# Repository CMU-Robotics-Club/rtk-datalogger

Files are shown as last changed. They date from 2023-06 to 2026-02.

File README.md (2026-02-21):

# Buggy Datalogger

[Software setup guide](https://docs.google.com/document/d/1eP9aE6b0Ft-kowX-BL1zWn5er9YviGEOUXOAjJxQ_KY/edit?tab=t.0)

Assembeled hardware:
<p align="center">
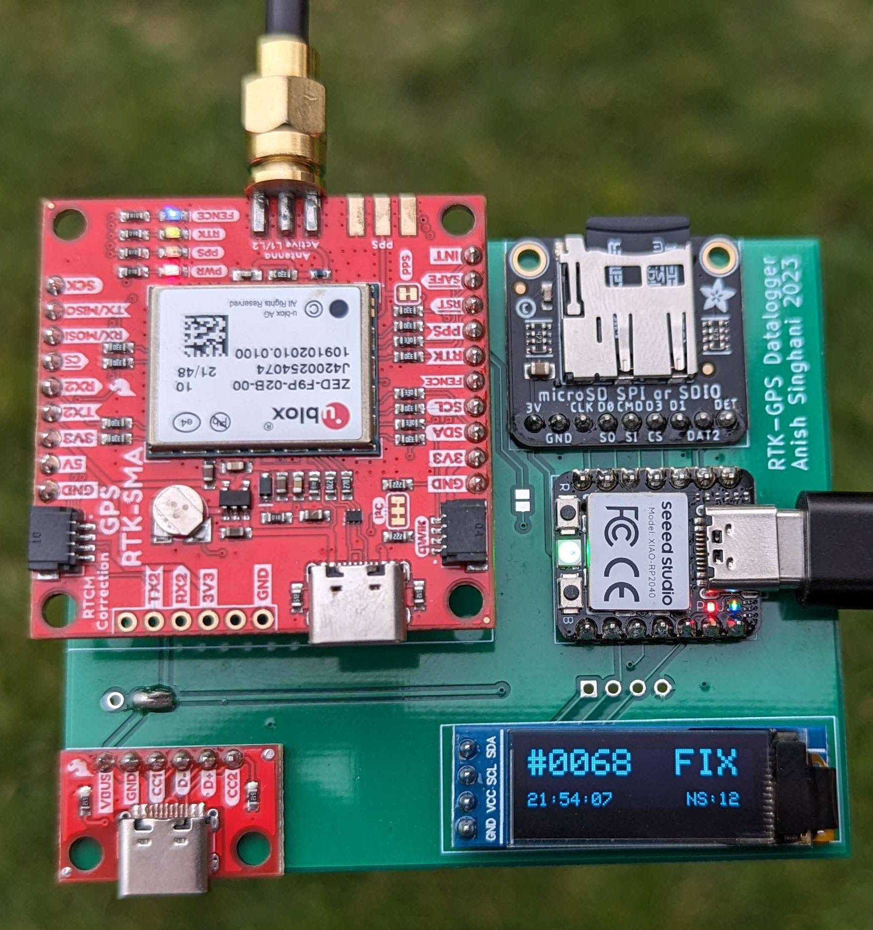
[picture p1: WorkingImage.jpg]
Image showing a module running a preliminary version of v1.0 Arduino firmware.

<p align="center">Image showing a module running a preliminary version of v1.0 Arduino firmware.</p>
</p>

[Project details](https://docs.google.com/document/d/1rpgdQh8PU_HBcYY4pXCmuHVJJGmpP6dXH_ktl7bgED4/edit?usp=sharing)

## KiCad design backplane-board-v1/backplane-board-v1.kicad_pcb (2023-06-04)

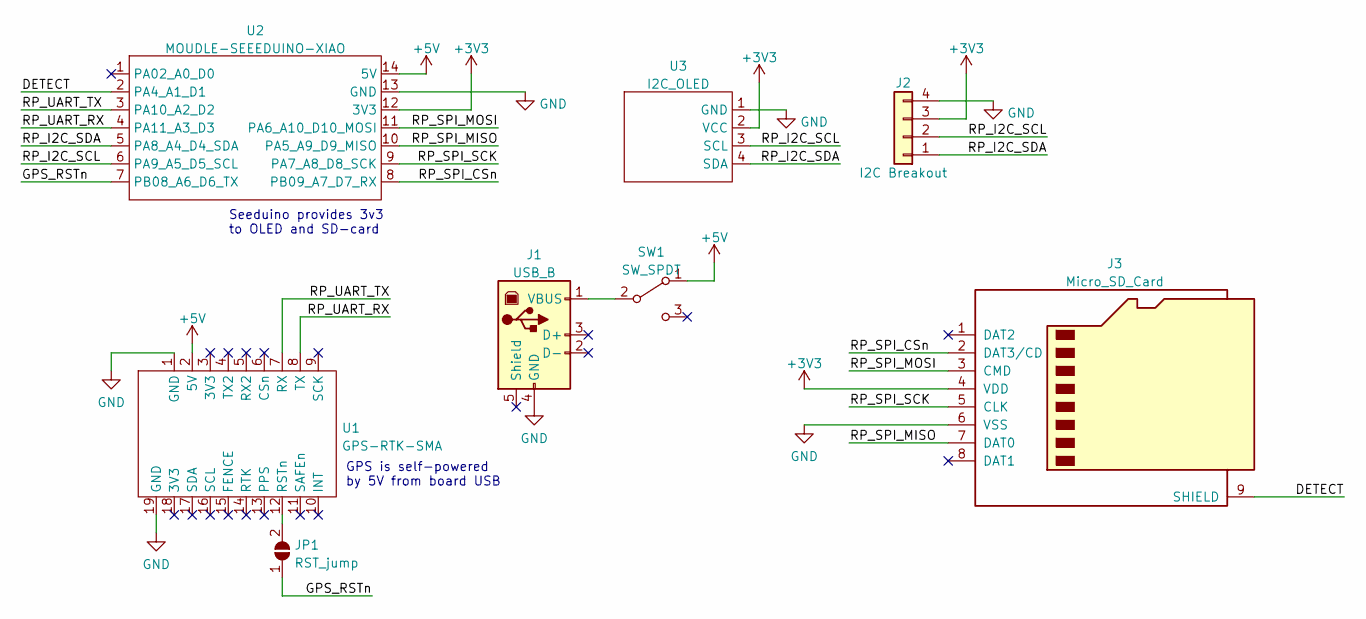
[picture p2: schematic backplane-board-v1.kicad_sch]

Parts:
J1: USB_B; sparkfun_usbc
J2: I2C Breakout; PinHeader_1x04_P2.54mm_Vertical
J3: Micro_SD_Card; adafruit_microsd
JP1: RST_jump; SolderJumper-2_P1.3mm_Open_Pad1.0x1.5mm
SW1: SW_SPDT; PinHeader_1x03_P2.54mm_Vertical
U1: GPS-RTK-SMA; gps-rtk-sma
U2: MOUDLE-SEEEDUINO-XIAO; MOUDLE14P-2.54-21X17.8MM
U3: I2C_OLED; i2c-oled

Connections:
+3V3: J2.3, J3.4 (VDD), U2.12 (3V3), U3.2 (VCC)
+5V: SW1.1 (A), U1.2 (5V), U2.14 (5V)
/DETECT: J3.9 (SHIELD), U2.2 (PA4_A1_D1)
/GPS_RSTn: JP1.1 (A), U2.7 (PB08_A6_D6_TX)
/RP_I2C_SCL: J2.2, U2.6 (PA9_A5_D5_SCL), U3.3 (SCL)
/RP_I2C_SDA: J2.1, U2.5 (PA8_A4_D4_SDA), U3.4 (SDA)
/RP_SPI_CSn: J3.2 (DAT3/CD), U2.8 (PB09_A7_D7_RX)
/RP_SPI_MISO: J3.7 (DAT0), U2.10 (PA5_A9_D9_MISO)
/RP_SPI_MOSI: J3.3 (CMD), U2.11 (PA6_A10_D10_MOSI)
/RP_SPI_SCK: J3.5 (CLK), U2.9 (PA7_A8_D8_SCK)
/RP_UART_RX: U1.8 (TX), U2.4 (PA11_A3_D3)
/RP_UART_TX: U1.7 (RX), U2.3 (PA10_A2_D2)
GND: J1.4 (GND), J2.4, J3.6 (VSS), U1.1 (GND), U1.19 (GND), U2.13 (GND), U3.1 (GND)
unnamed: J1.1 (VBUS), SW1.2 (B)
unnamed: JP1.2 (B), U1.12 (RSTn)

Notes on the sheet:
Seeduino provides 3v3 to OLED and SD-card
GPS is self-powered by 5V from board USB

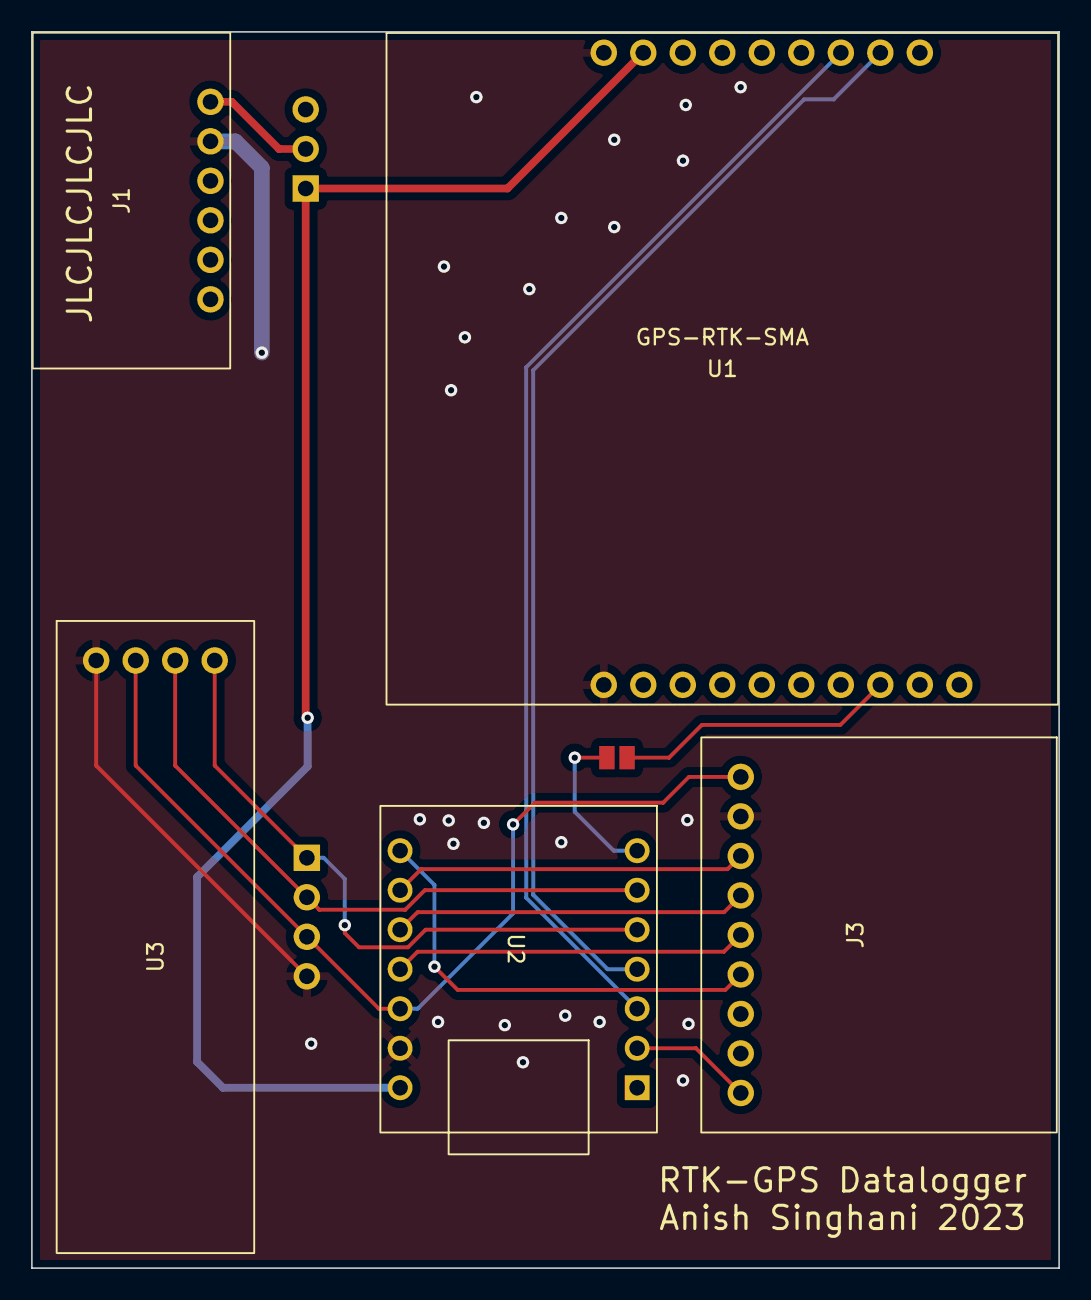
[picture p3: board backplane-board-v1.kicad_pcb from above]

Board: 2 copper layers, 66.0 x 79.5 mm, 8 parts (0 on the bottom side), 15 nets.

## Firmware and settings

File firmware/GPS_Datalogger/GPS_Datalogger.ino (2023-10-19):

// GPS Datalogger Arduino Firmware v1.0
//  for RTK-GPS Datalogger, A.S. 2023
//  (Seeed XIAO RP2040 + Sparkfun ZED-F9P breakout)
// By Robert Mones

#define PIN_SD_MOSI 3
#define PIN_SD_MISO 4
#define PIN_SD_SCK  2
#define PIN_SD_SS   1

#include <SPI.h>
#include <RP2040_SD.h>

#include <Adafruit_NeoPixel.h>
#include <Adafruit_GFX.h>
#include <Adafruit_SSD1306.h>
#include <splash.h>

// Uncomment the following line to enable debug mode
//  In debug mode, some testing data is printed to the USB serial port
//  and the system does not start until something is sent to it via the
//  USB serial port. The device will still print error messages via the
//  USB serial port regardless of this setting.
// #define DEBUG

// Size of the data buffer (in bytes)
#define BUFSIZE (1024*32)
// Minimum amount of data to copy from the buffer to the SD card
#define WRITESIZE (1024*1)

// Hardware UART interface to communicate with the GPS module
SerialPIO gps_uart(28, 29);
int fixtype = 0;

// NeoPixel object to control the onboard RGB LED
Adafruit_NeoPixel rgb(1, 12, NEO_GRB + NEO_KHZ800);
uint32_t ledtime = 0;
bool ledstate = 0;

// Display object to communicate with the SSD1306 display over I2C
Adafruit_SSD1306 disp(128, 32, &Wire, -1);

// Data buffers and their respective sizes
size_t bufct = 0;
size_t bufcpyct = 0;
size_t bufctmax = 0;
uint8_t buf[BUFSIZE];
uint8_t bufcpy[BUFSIZE];

// File object which is being written to on the SD card
char fname[30];
File datafile;

// Flag which is set if an error occurs
volatile bool error_flag = false;
// Helper function which flashes the RGB led red, prints an error message to the display
//  (if msg != NULL), and prints an error message to the USB serial port (if dbgmsg != NULL)
void error(char *msg, char *dbgmsg) {
  error_flag = true;
  delay(1000);
  rgb.clear();
  rgb.setPixelColor(0, rgb.Color(127,0,0));
  rgb.show();

  if(dbgmsg != NULL) {
    Serial.println(dbgmsg);
  }

  if(msg != NULL) {
    disp.clearDisplay();
    disp.setTextSize(2);
    disp.setCursor(0,0);
    disp.write(msg);
    disp.display();
  }

  while(true) {
    rgb.clear();
    rgb.setPixelColor(0, rgb.Color(127,0,0));
    rgb.show();
    delay(250);
    rgb.clear();
    rgb.setPixelColor(0, rgb.Color(0,0,0));
    rgb.show();
    delay(250);
  }
}

void setup() {
  // Init debug USB serial port
  Serial.begin(115200);
  #ifdef DEBUG
  while(!Serial.available());
  while(Serial.available()) Serial.read();
  Serial.println("Starting GPS Datalogger");
  #endif

  // Init RGB led
  rgb.begin();
  pinMode(11, OUTPUT);
  digitalWrite(11, HIGH);
  rgb.clear();
  rgb.setPixelColor(0, rgb.Color(31,31,0));
  rgb.show();

  // Init display
  if(!disp.begin(SSD1306_SWITCHCAPVCC, 0x3C)) {
    error(NULL, "FAILED TO INIT DISPLAY");
  }
  disp.clearDisplay();
  disp.setTextSize(2);
  disp.setTextColor(SSD1306_WHITE);
  disp.display();

  memset(buf, 0, BUFSIZE);
  memset(bufcpy, 0, BUFSIZE);

  // Init SD card
  SPI.setRX(PIN_SD_MISO);
  SPI.setCS(PIN_SD_SS);
  SPI.setSCK(PIN_SD_SCK);
  SPI.setTX(PIN_SD_MOSI);
  if (!SD.begin(PIN_SD_SS)) {
    error("NO SD CARD", "FAILED TO INIT SD CARD");
  }
  // Search for filename
  for (uint32_t i = 0; i < 10000; i++) {
    sprintf(fname, "DATA%04d.BIN", i);
    if (!SD.exists(fname)) break;
  }
  // Create the new file and overwrite if existing, but this won't happen
  //  until file cap is reached
  if (SD.exists(fname)) SD.remove(fname);
  datafile = SD.open(fname, FILE_WRITE);
  if (!datafile) {
    char printbuf[40];
    sprintf(printbuf, "FAILED TO OPEN FILE %s", fname);
    error("FAILED TO OPEN FILE", printbuf);
  }
  #ifdef DEBUG
  Serial.print("uSD Card initialized -- writing to ");
  Serial.println(fname);
  #endif
  // Delay to let everything power up
  delay(1000);

  // Tell other core to begin loop and wait for it to be ready
  rp2040.fifo.push(1);
  rp2040.fifo.pop();
}

void loop() {
  // Check buffer usage
  if (bufct > WRITESIZE) {
    if(bufct > bufctmax) bufctmax = bufct;
    // Ask for custody of buf from core1 and proceed on positive response
    rp2040.fifo.push_nb(1);
    if (rp2040.fifo.pop() == 1) {
      // Copy buf to bufcpy
      memcpy(bufcpy, buf, bufct);
      bufcpyct = bufct;
      bufct = 0;
      // Finish copy by giving custody of buf back to core1
      rp2040.fifo.push(0);

      // Write copied data to SD card
      if(datafile.write(bufcpy, bufcpyct) < bufcpyct) {
        error("FILE WRITE  FAILED", "FAILED TO WRITE TO FILE");
      }
      datafile.flush();

      #ifdef DEBUG
      Serial.print("Wrote ");
      Serial.print(bufcpyct);
      Serial.println(" bytes");
      #endif

      // Parse GNGGA NMEA packet to get utc time, fix type, and number of satellites
      // Start from end of data being written to only consider latest packet
      size_t nmea_start = 0;
      size_t nmea_end = 0;
      size_t i = bufcpyct - 1;
      for(; i >= 4; i--) {
        // Look for end of NMEA packet
        if(bufcpy[i-4] == '*' &&
            ((bufcpy[i-3] >= '0' && bufcpy[i-3] <= '9') || (bufcpy[i-3] >= 'A' && bufcpy[i-3] <= 'F')) &&
            ((bufcpy[i-2] >= '0' && bufcpy[i-2] <= '9') || (bufcpy[i-2] >= 'A' && bufcpy[i-2] <= 'F')) &&
            bufcpy[i-1] == '\r' && bufcpy[i] == '\n') {
          nmea_end = i-1; // Exclusive end of NMEA string
          break;
        }
      }
      for(; i >= 1; i--) {
        // Look for start of NMEA packet
        if(strncmp("$GNGGA", (char*)(bufcpy+i-1), 6) == 0) {
          nmea_start = i-1; // Inclusive start of GNGGA NMEA string
          break;
        }
      }
      size_t nmea_len = nmea_end - nmea_start;
      if(nmea_len >= 6 && nmea_len <= 82) {
        // Found valid GNGGA NMEA packet
        char gnggabuf[100];
        memcpy(gnggabuf, bufcpy+nmea_start, nmea_len);
        // Need to separate commas and replace with spaces to support easy sscanf parsing
        for(size_t j = 1; j < nmea_len; j++) {
          if(gnggabuf[j-1] == ',' && gnggabuf[j] == ',') {
            memmove(gnggabuf+j+1, gnggabuf+j, nmea_len-j);
            gnggabuf[j] = 'x';
            nmea_len++;
          }
        }
        for(size_t j = 0; j < nmea_len; j++) {
          if(gnggabuf[j] == ',') gnggabuf[j] = ' ';
        }
        gnggabuf[nmea_len] = '\0';

        #ifdef DEBUG
        Serial.print("Extracted packet '");
        Serial.print(gnggabuf);
        Serial.println("'");
        #endif

        // Parse relevant information from packet
        char utcbuf[10];
        int tmpfixtype = -1;
        int numsats = -1;
        int parsect = sscanf(gnggabuf, "$GNGGA %s %*s %*s %*s %*s %d %d %*s %*s %*s %*s %*s *%*s", utcbuf, &tmpfixtype, &numsats);
        utcbuf[9] = '\0';
        
        #ifdef DEBUG
        Serial.print("Parsed (");
        Serial.print(parsect);
        Serial.print(") ");
        Serial.print(utcbuf);
        Serial.print(" time, ");
        Serial.print(fixtype);
        Serial.print(" fix, ");
        Serial.print(numsats);
        Serial.println(" satellites");
        #endif

        // If parse succeeded, proceed with storing fix type in global variable and
        //  write to display
        if(parsect == 3) {
          fixtype = tmpfixtype;
          // Write to display
          disp.clearDisplay();
          disp.setTextSize(2);
          disp.setCursor(0,0);
          char printbuf[11];
          sprintf(printbuf, "#%c%c%c%c  %s", fname[4], fname[5], fname[6], fname[7], (fixtype > 0) ? "FIX" : "---");
          disp.write(printbuf);
          disp.write("\n");
          int utchr = -1;
          int utcmin = -1;
          int utcsec = -1;
          sscanf(utcbuf, "%02d%02d%02d.%*02d", &utchr, &utcmin, &utcsec);
          sprintf(printbuf, "%02d:%02d:%02d     Sats:%02d", utchr, utcmin, utcsec, numsats);
          disp.setTextSize(1);
          disp.write("\n");
          disp.write(printbuf);
          disp.display();
        }
      }
      
      delay(10);
    }
  }

  // Flash RGB LED blue if no fix and green if fix
  uint32_t t = millis();
  if(t - ledtime > 500) {
    ledtime = t;
    ledstate = !ledstate;
    
    rgb.clear();
    rgb.setPixelColor(0, ledstate ? (fixtype > 0 ? rgb.Color(0,31,0) : rgb.Color(0,0,63)) : rgb.Color(0,0,0));
    rgb.show();
  }

  // Halt while error_flag is set to true
  while(error_flag);
}

void setup1() {
  // Open the hardware UART port to the GPS module
  gps_uart.begin(460800);

  // Wait for the other core to be ready and tell it this core is ready
  rp2040.fifo.pop();
  rp2040.fifo.push(1);
}

void loop1() {
  // Read the data from the GPS module into the buffer
  while (gps_uart.available()) {
    buf[bufct] = gps_uart.read();
    bufct++;
    if(bufct >= BUFSIZE) {
      error("BUFFER    OVERFLOW", "BUFFER OVERFLOW");
    }
  }
  uint32_t coremsg;
  // Check if a request for buf custody is present
  if (rp2040.fifo.pop_nb(&coremsg) && coremsg == 1) {
    // Respond giving custody to core0
    rp2040.fifo.push_nb(1);
    // Wait for custody back from core1
    uint32_t t1 = micros();
    while (rp2040.fifo.pop() != 0);
    uint32_t t2 = micros();
    #ifdef DEBUG
    Serial.print("Waited ");
    Serial.print(t2 - t1);
    Serial.println(" us");
    #endif
  }

  // Halt while error_flag is set to true
  while(error_flag);
}

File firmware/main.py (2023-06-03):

import machine
import sdcard
import uos
import time
import _thread
import hashlib
import neopixel


SPI_PERIPH = 1
CS_PIN = 9
SCK_PIN = 14
MOSI_PIN = 15
MISO_PIN = 12
SD_BAUD = 25000000

UART_PERIPH = 0
UART_TX_PIN = 28
UART_RX_PIN = 29
UART_BAUD = 230400

WS2812_PIN = 8

BLOCK_SIZE = 16
WRITE_CHUNK_SIZE = 8192
CHUNK_SIZE = 1*WRITE_CHUNK_SIZE
FILE_TIME = 5 # seconds

WDT_TIMER = 7000 # watchdog timeout, millis

DO_ENCRYPT = False
ENCRYPT_KEY = ""

VERSION = "0.1.4"

# TODO: This is effectively just a shim. need 
# to implement proper asymmetric-key encryption
# with the key stored on the SD card. This will
# ensure that the key used for decryption is not
# stored anywhere on the embedded device.
def encrypt(plaintext, iv):
    if DO_ENCRYPT:
        cipher = hashlib.sha256(ENCRYPT_KEY+iv).digest()
        ciphertext = bytearray([plaintext[i] ^ cipher[i % BLOCK_SIZE]
                      for i in range(len(plaintext))])
        return iv, ciphertext
    else:
        return iv, plaintext

def panic(reason):
    while True:
        print("PANIC:", reason)
        time.sleep(1)

def setup_sdcard():
    cs = machine.Pin(CS_PIN, machine.Pin.OUT)
    spi = machine.SPI(SPI_PERIPH, baudrate=SD_BAUD,
        polarity=0, phase=0, bits=8,
        firstbit=machine.SPI.MSB,
        sck=machine.Pin(SCK_PIN),
        mosi=machine.Pin(MOSI_PIN),
        miso=machine.Pin(MISO_PIN))

    sd = sdcard.SDCard(spi, cs)

    vfs = uos.VfsFat(sd)
    uos.mount(vfs, "/sd")

def get_next_index():
    cur_idx = None
    try:
        with open("/sd/index.txt", "r") as f:
            cur_idx = int(f.read().strip())
    except:
        pass

    if cur_idx:
        try:
            with open("/sd/index.txt", "w+") as f:
                f.write(str(cur_idx+1))
            return cur_idx+1
        except:
            panic("Failed to increment index")
    else:
        try:
            with open("/sd/index.txt", "w+") as f:
                f.write(str(1))
            return 1
        except:
            panic("Failed to create new index file")

def get_next_filename():
    wdt.feed();
    idx = get_next_index()
    fn = "/sd/gps{:06d}.txt".format(idx)

    wdt.feed();
    print("Starting file", fn)
    with open(fn, "w+") as f:
        f.write("GPS")

    return fn

def setup_all():
    global uart, led
    uart = machine.UART(UART_PERIPH, baudrate=UART_BAUD,
                        tx=machine.Pin(UART_TX_PIN),
                        rx=machine.Pin(UART_RX_PIN))
    uart.init(bits=8, parity=None, stop=1)

    led = neopixel.NeoPixel(machine.Pin(WS2812_PIN, machine.Pin.OUT), 1)
    led[0] = (0, 0, 255)
    led.write()
    led.write()

    setup_sdcard()


shared_buffer = bytearray()
shared_lock = _thread.allocate_lock()

last_uart = 0
last_datalog = 0

led_state = 0

def uart_thread():
    global uart, led, led_state, last_uart, last_datalog

    dat_pending = bytearray()
    while True:
        time.sleep_us(10)

        is_good = ((time.ticks_ms() - last_uart) < 10000) and ((time.ticks_ms() - last_datalog) < 10000)

        if is_good and (time.ticks_ms() % 500) < 350:
            if led_state == 1:
                led_state = 0
                led[0] = (0, 0, 0)
                led.write()
        else:
            if led_state == 0:
                led_state = 1
                led[0] = (0, 255, 0)
                led.write()

        dat = uart.read()
        if dat:
            dat_pending.extend(dat)
            last_uart = time.ticks_ms()

        if len(dat_pending):
            if shared_lock.acquire(0):
                shared_buffer.extend(dat_pending)
                dat_pending = bytearray()
                shared_lock.release()

        if len(dat_pending) > 4096:
            with shared_lock:
                shared_buffer.extend(dat_pending)
                dat_pending = bytearray()

def sdcard_thread():
    global shared_lock, shared_buffer, wdt, last_datalog

    print("HELLO FROM DATALOGGER", VERSION)
    wdt = machine.WDT(timeout=WDT_TIMER)

    last_write = 0

    wdt.feed();
    cur_file = get_next_filename()

    while True:
        wdt.feed();
        with shared_lock:
            l = len(shared_buffer)
        wdt.feed();

        # No TOCTOU here because uart_thread only ever
        # extends shared_buffer, never shortens it
        if (l > CHUNK_SIZE) or ((l > BLOCK_SIZE) and (time.time() - last_write > FILE_TIME)):
            _start = time.ticks_ms()

            wdt.feed();
            with shared_lock:
                n = len(shared_buffer)
                n = n - (n % BLOCK_SIZE)
                tmp_buffer = shared_buffer[:n]
                shared_buffer = shared_buffer[n:]

            with open(cur_file, "a+") as f:
                for i in range(0, len(tmp_buffer), WRITE_CHUNK_SIZE):
                    wdt.feed();
                    f.write(encrypt(tmp_buffer[i:i+WRITE_CHUNK_SIZE], cur_file)[1])

            # Cycle out the files
            if time.time() - last_write > FILE_TIME:
                cur_file = get_next_filename()
                last_write = time.time()

            wdt.feed();
            print("WRITE TIME", time.ticks_ms() - _start)
            last_datalog = time.ticks_ms()

# Startup routine
setup_all()
_thread.start_new_thread(uart_thread, ())
sdcard_thread()

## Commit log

2023-06-04 Add backplane PCB
    [backplane-board-v1.kicad_pcb, backplane-board-v1.kicad_sch]
2023-10-18 Replaced python firmware with Arduino firmware v0.1
    Currently logs all data from GPS module UART1 port and displays file number and maximum buffer size (for debugging)
    [GPS_Datalogger.ino, main.py]
2023-10-19 Updated to v0.2 firmware and backed up GPS config
    Increased UART bandwidth (on GPS and microcontroller) to achieve 10Hz rates on all messages
    Also stored GPS ZED-F9P configuration to file for backup
    [config_10_18_23.txt]
2023-10-19 Fixed file version number
    [GPS_Datalogger.ino]
2023-10-19 Updated to v1.0 Arduino firmware
    Firmware now:
    - Prints error messages to the display
    - Uses the Seeed XIAO RP2040's onboard NeoPixel RGB LED to display status (yellow in startup, flash red in error, flash blue if no fix, flash green if fix)
    - Added error helper function to facilitate above error-displaying features
    - Catches additional error cases
    - Parses NMEA data to display the UTC time, number of satellites, and fix status to the display
    - Added DEBUG flag which limits USB serial data to error messages only if not set and waits until USB serial data is received to start if set
    [GPS_Datalogger.ino]
2023-10-19 Added GPS config for v1.0 firmware
    Also renamed GPS config for v0.2 firmware to match
    [config_v0.2.txt, config_v1.0.txt]
2023-10-19 Upload WorkingImage.jpg
    Added WorkingImage.jpg, which displays a module running a preliminary version of v1.0 Arduino firmware
